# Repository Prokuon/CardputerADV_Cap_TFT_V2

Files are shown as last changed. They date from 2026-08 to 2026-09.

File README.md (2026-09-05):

# Cap TFT V2 - 2.8 Inch Display Expansion for Cardputer ADV

Cap TFT V2 is a display expansion module designed for Cardputer ADV, featuring an integrated 2.8 inch ILI9341 display (320x240)

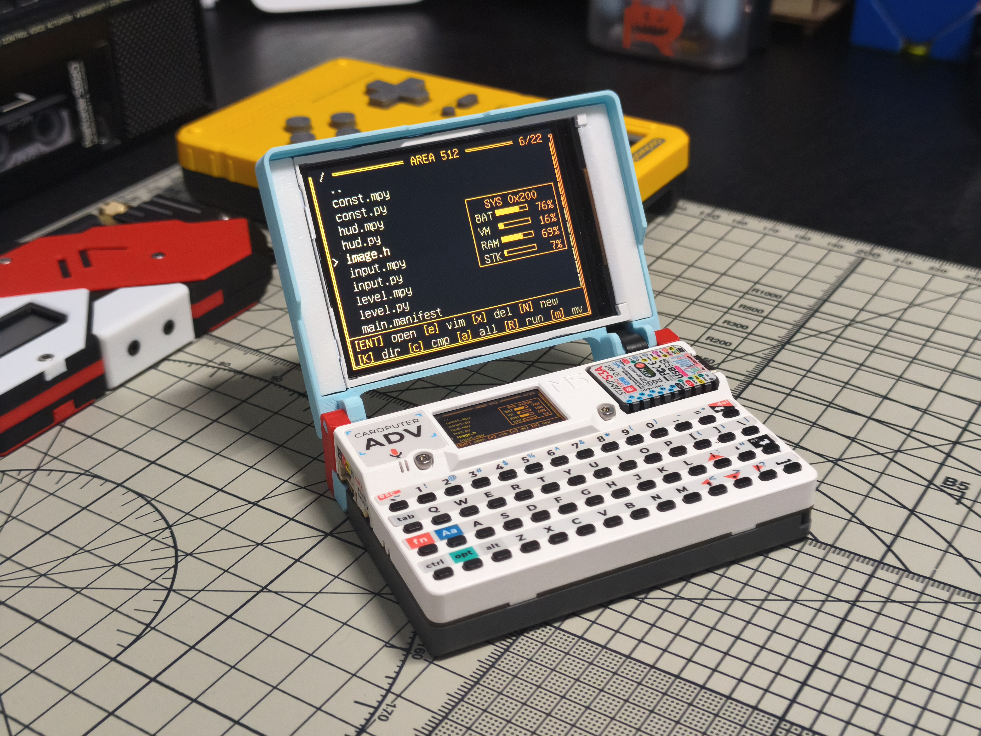
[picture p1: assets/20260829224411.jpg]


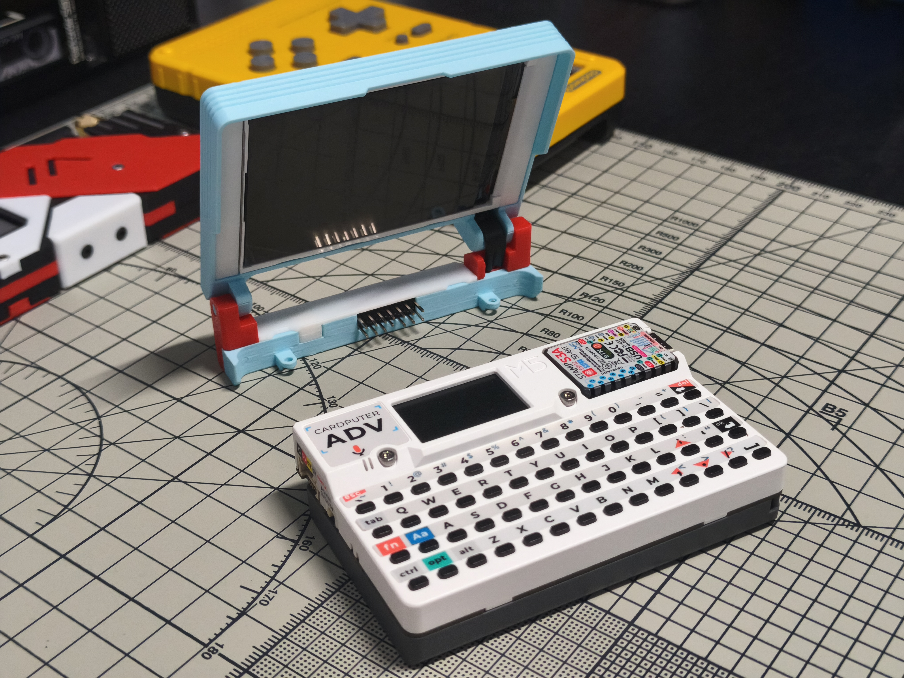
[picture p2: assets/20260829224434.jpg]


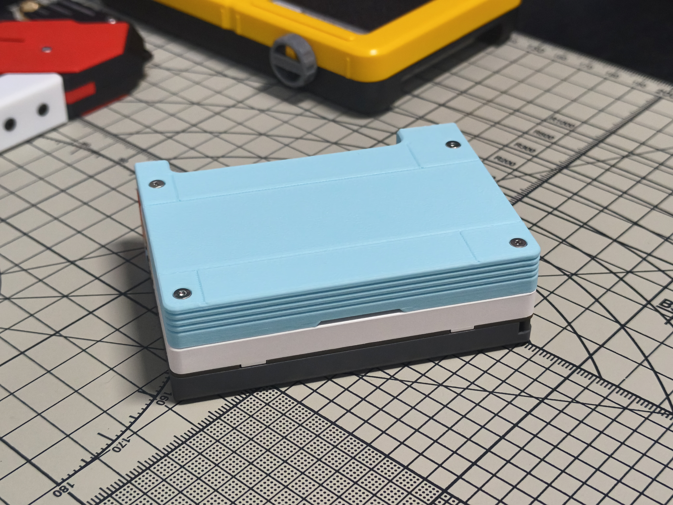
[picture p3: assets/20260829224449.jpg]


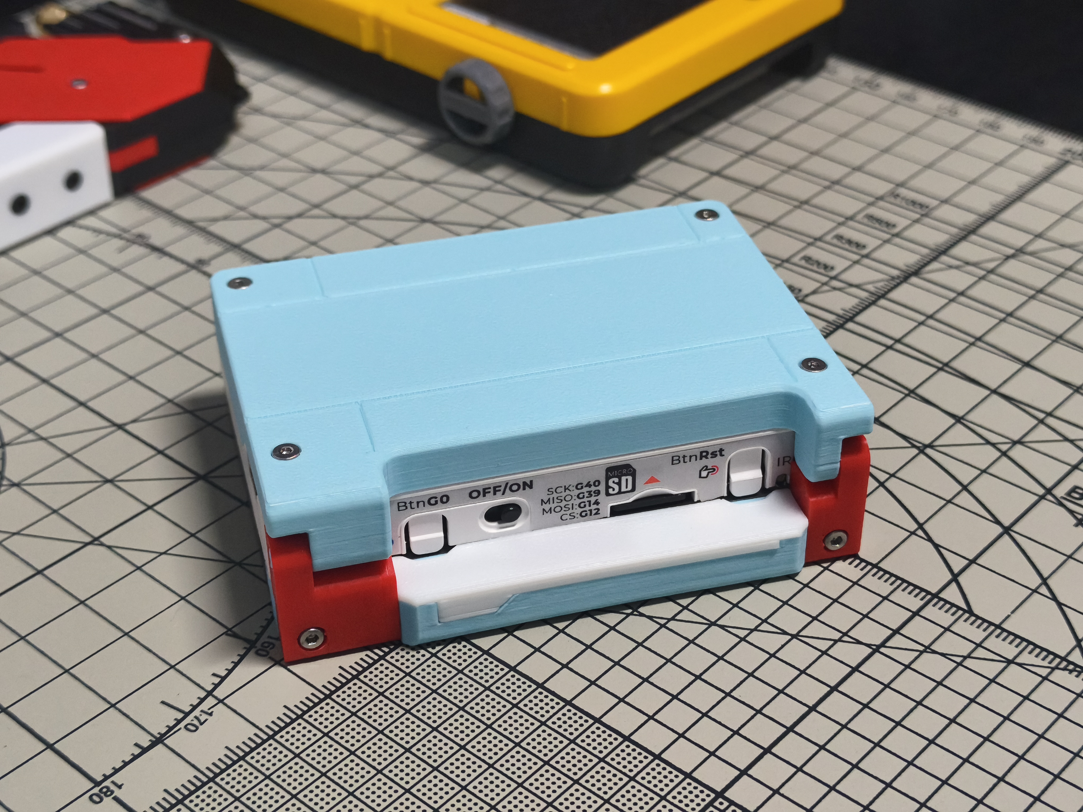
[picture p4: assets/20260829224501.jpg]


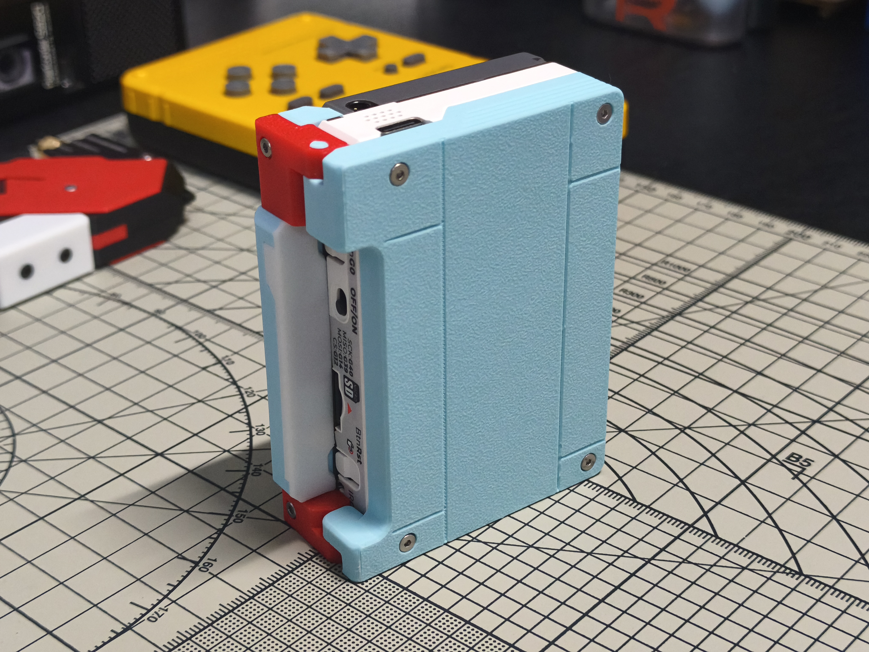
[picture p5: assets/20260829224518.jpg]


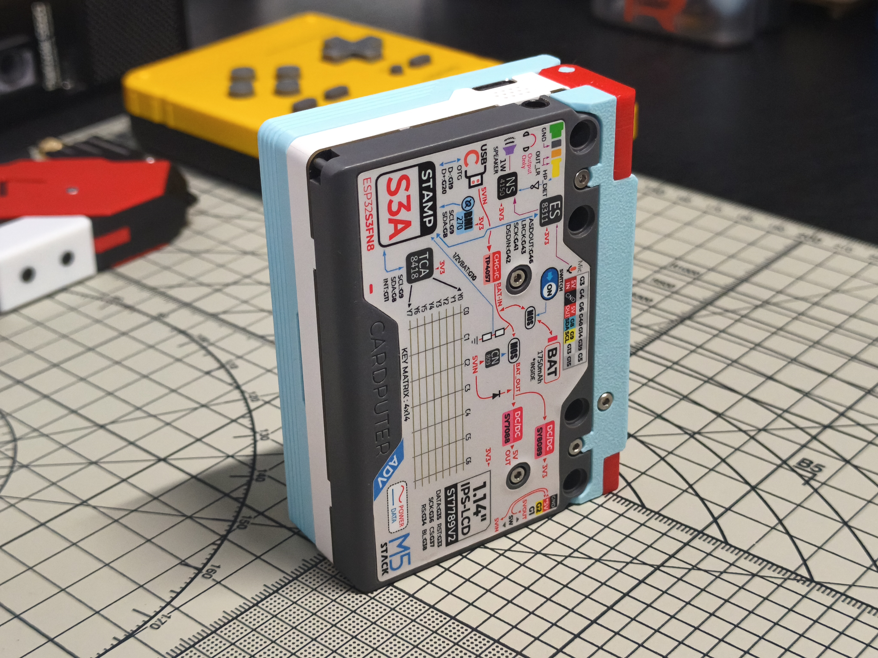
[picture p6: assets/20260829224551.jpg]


## BOM List

1. 3D printed shell D1
2. 3D printed shell D2
3. 3D printed shell D3
4. 3D printed shell L1
5. 3D printed shell R1
6. 3D printed shell S1
7. 3D printed shell C1
8. 2.8 inch ILI9341 display
9. M2x5 hex socket flat head bolts - 4 pieces
10. M2x5 hex socket cap bolts - 3 pieces
11. 2.54mm 2x7P dual-row straight pin header
12. Power supply module (AMS1117-3.3V)

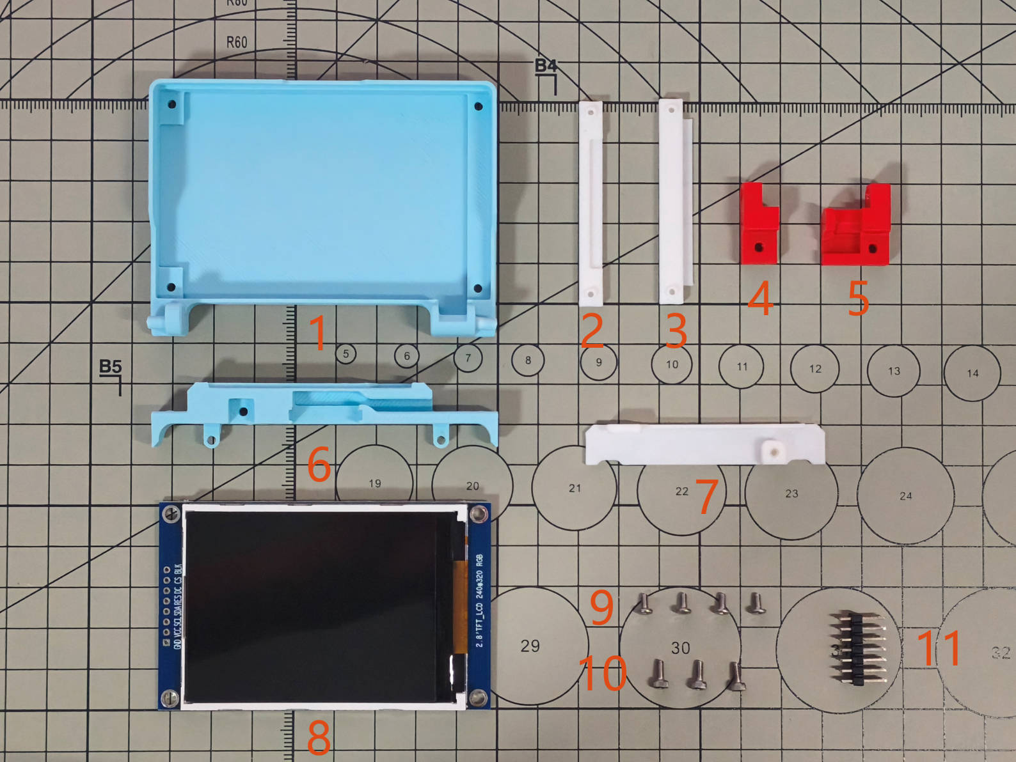
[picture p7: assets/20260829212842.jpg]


Display dimension specifications

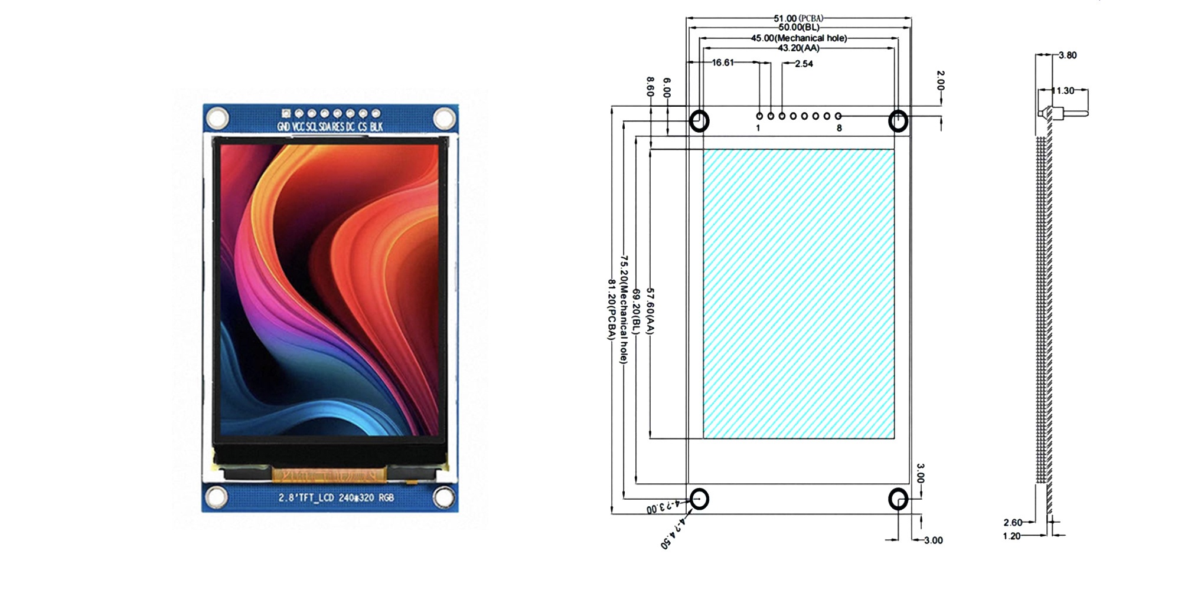
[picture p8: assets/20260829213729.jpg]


Power supply module reference image

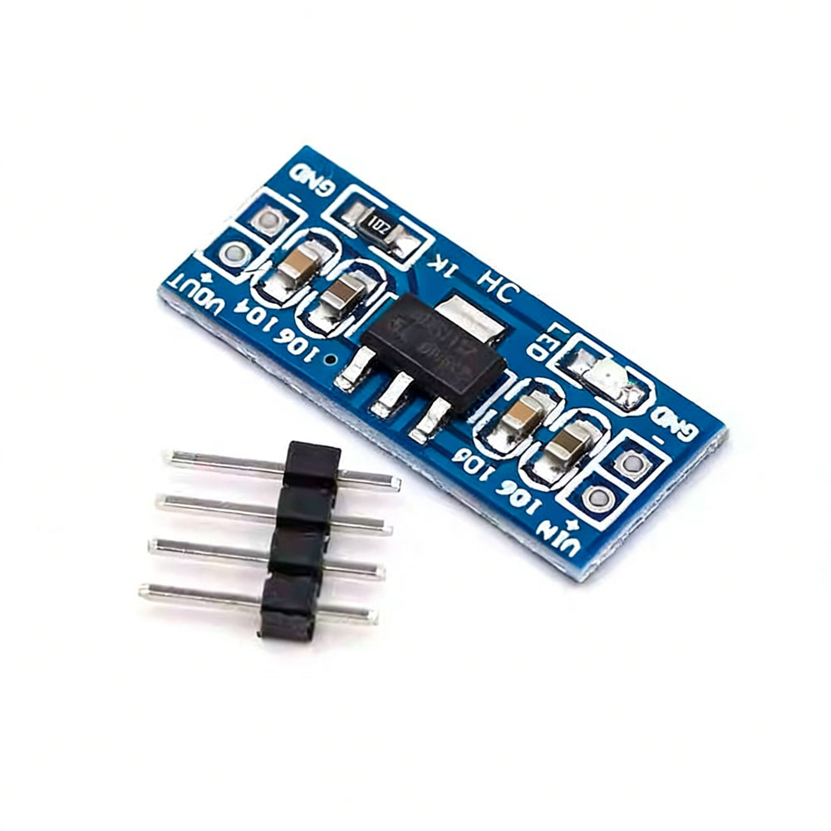
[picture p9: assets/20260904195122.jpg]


## Assembly Instructions

Attach the power supply module to the back of the display, and connect the display to the pin header using thin wires as shown in the diagram. It is recommended to use cable with an outer diameter of 0.65mm. For the wiring definition, please refer to the table below.

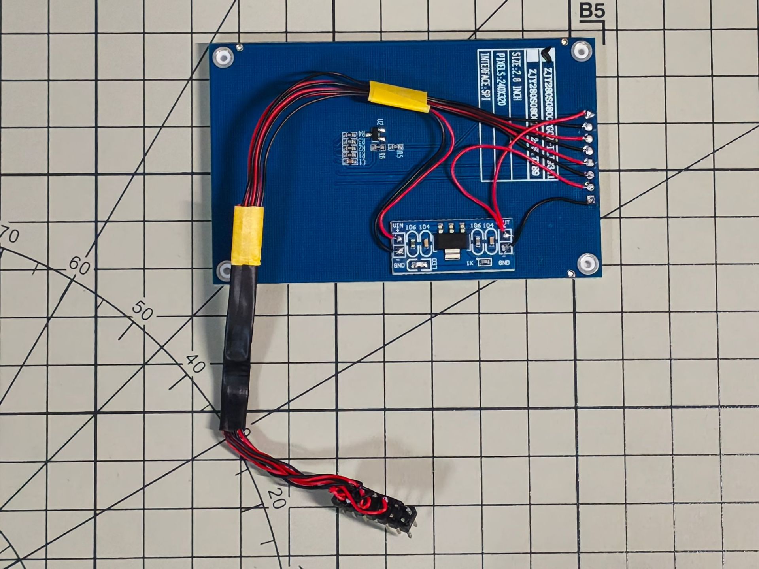
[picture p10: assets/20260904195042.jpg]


Display

| GND  | VCC  | SCL  | SDA  | RES  | DC | CS | BLK  |
| :--: | :--: | :--: | :--: | :--: | :--: | :--: | :--: |
| 1 | 2 | 3 | 4 | 5 | 6 | 7 | 8 |

Power supply module

| VIN  | VOUT |
| :--: | :--: |
| 10 | 2, 8 |
| GND  | GND  |
| 9 | 1 |

Cardputer

| G3 | G4 | G6 | G40  | G14  | G39  | G5 |
| :--: | :--: | :--: | :--: | :--: | :--: | :--: |
| 5 | x | 6 | 3 | 4 | x | 7 |
| 5VIN | GND  | 5VOUT| SDA  | SCL  | G13  | G15  |
| x | 9 | 10 | x | x | x | x |

Install the display onto D1

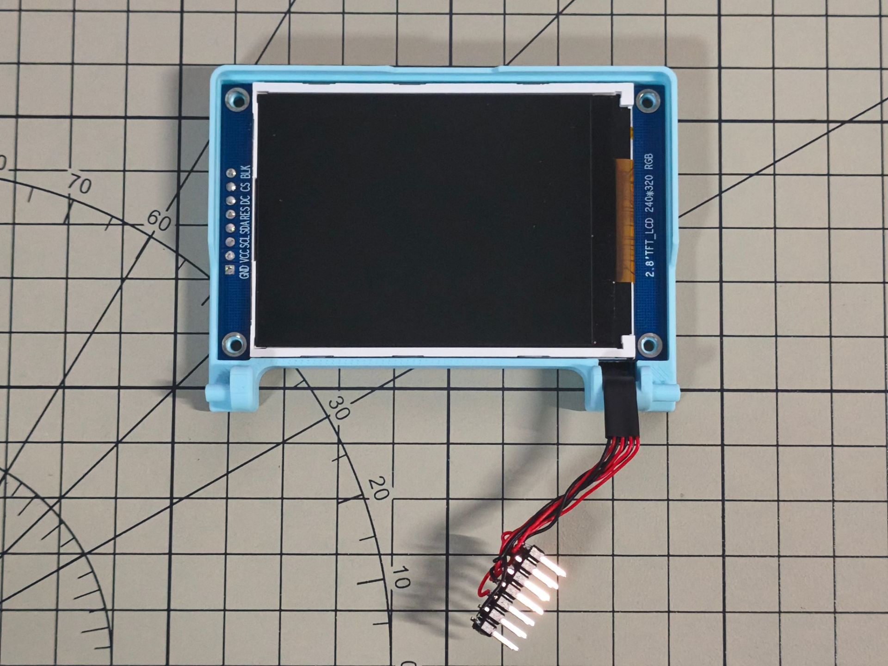
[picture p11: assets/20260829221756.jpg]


Use 4 M2x5 hex socket flat head bolts to install D2 and D3 onto D1

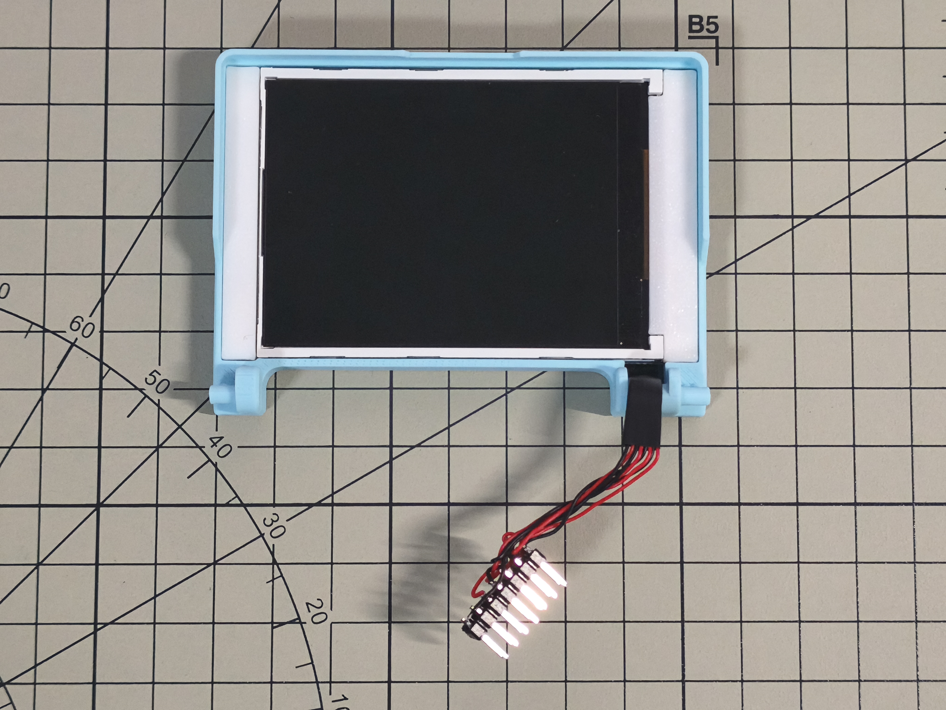
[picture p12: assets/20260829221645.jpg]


Install the pin header onto S1

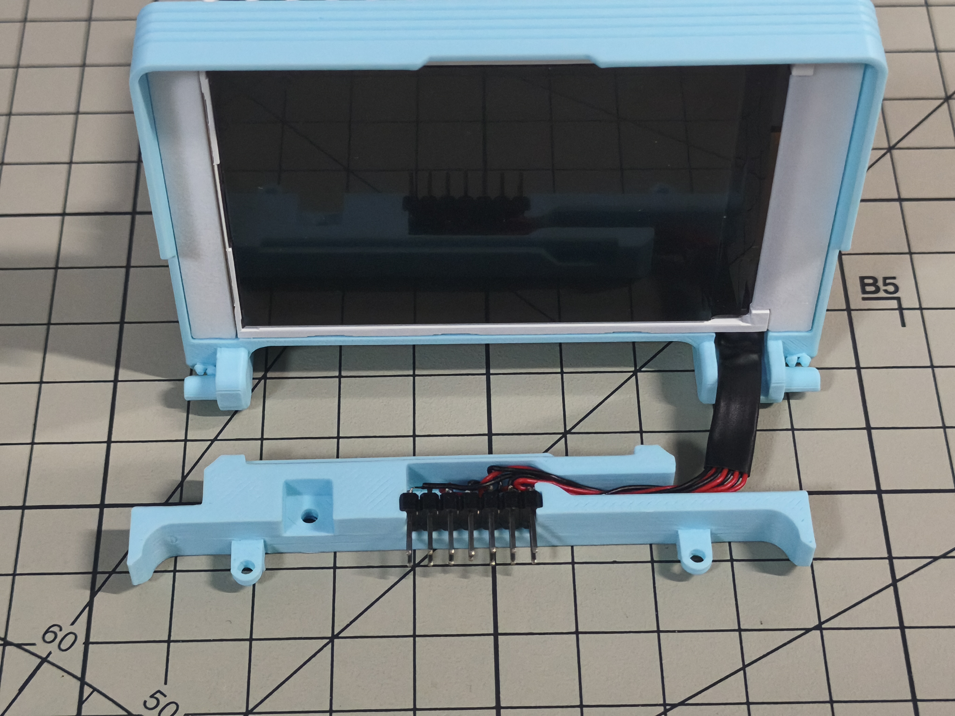
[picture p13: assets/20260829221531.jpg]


Use 1 M2x5 hex socket cap bolt to assemble C1 and S1

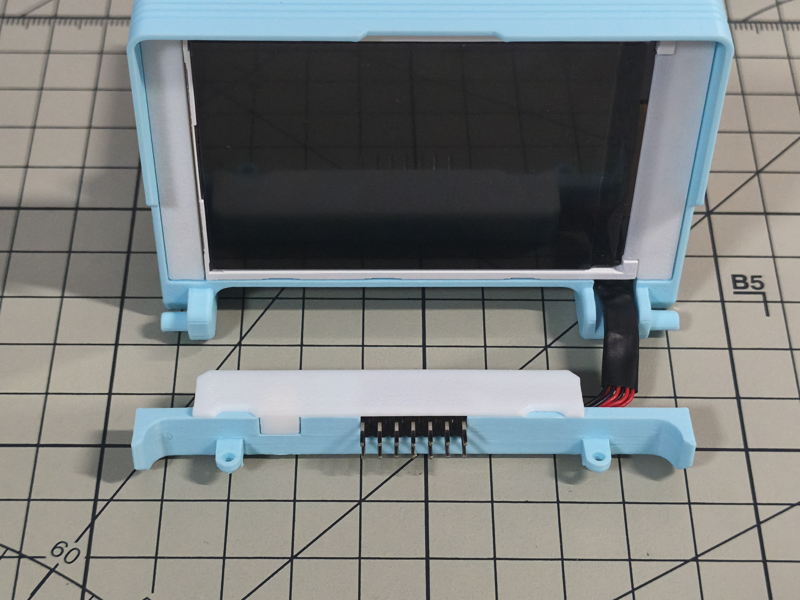
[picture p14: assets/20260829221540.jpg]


Install L1 and R1 onto D1

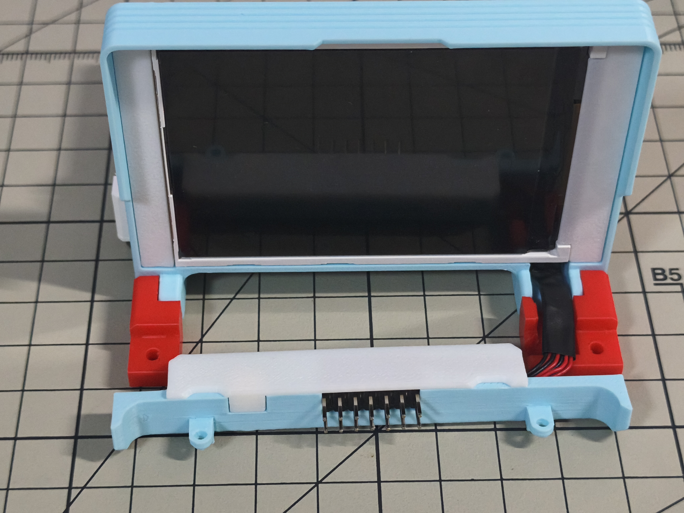
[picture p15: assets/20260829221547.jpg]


Use 2 M2x5 hex socket cap bolts to install L1 and R1 onto S1

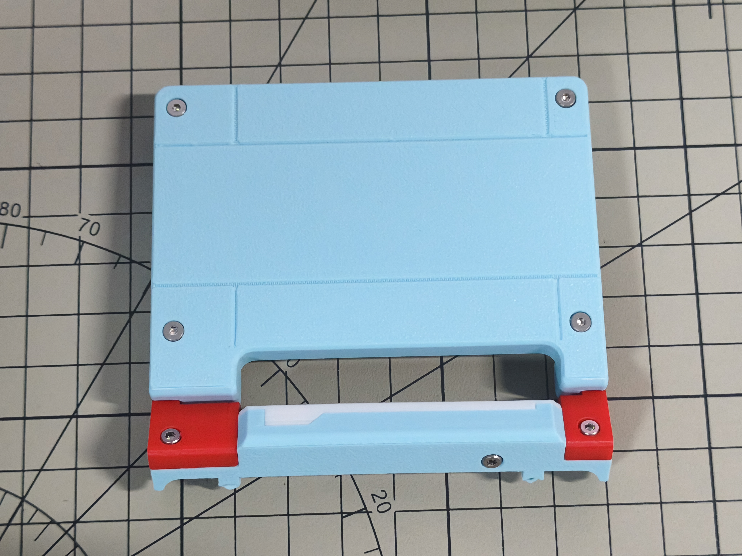
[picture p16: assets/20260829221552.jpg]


Assembly complete

## Credits

- The selection of the new display was inspired by the expansion screen designed by tipflow for Cardputer ADV. Project link: [M5 Cardputer Extended Screen](https://makerworld.com/zh/models/3054465-m5-cardputer-extended-screen?from=search#profileId-3436513)
- The firmware used for the display expansion is modified based on engneer-hamachan's [area512](https://github.com/engneer-hamachan/area512). It is a great retro OS, styled similarly to the handheld Cyberdeck used by the TVA in the TV series Loki

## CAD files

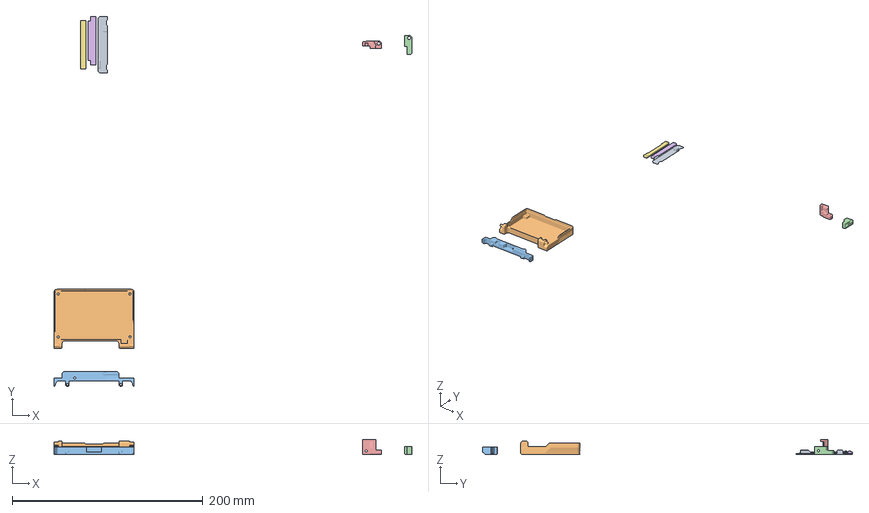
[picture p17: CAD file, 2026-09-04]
Model/CapTFT_V2.3mf
375.2 x 387.8 x 16.0 mm
CaseC1.stl
CaseD1.stl
CaseS1.stl
CaseL1.stl
CaseR1.stl
CaseD3.stl
CaseD2.stl

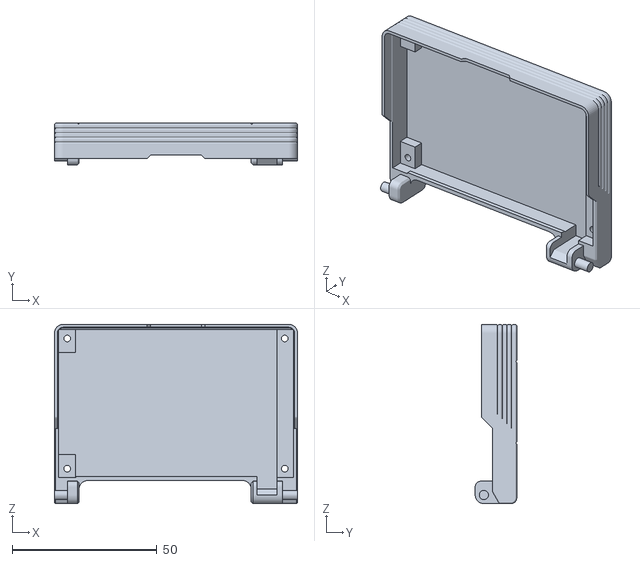
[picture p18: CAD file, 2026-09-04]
Model/STL/CaseD1.stl
84.0 x 14.4 x 62.0

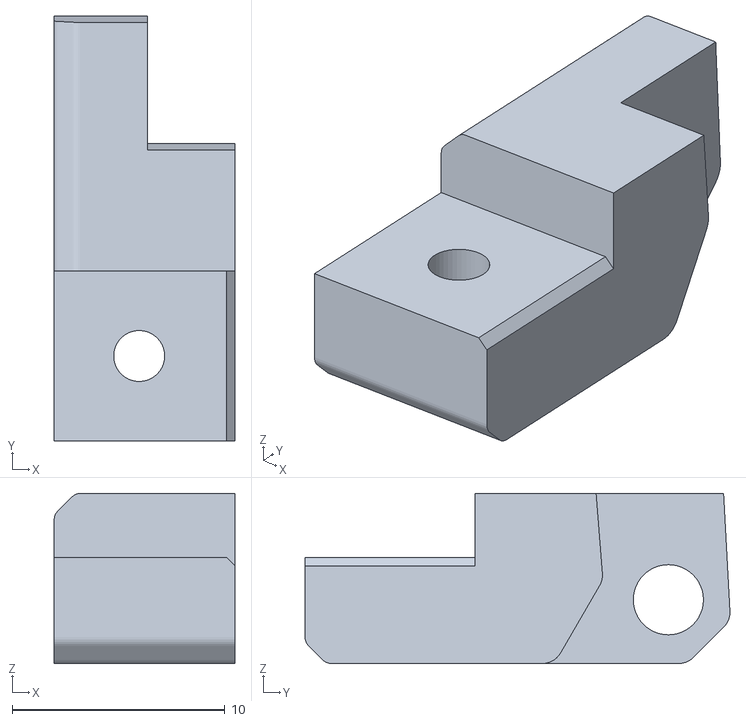
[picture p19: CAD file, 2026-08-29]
Model/STL/CaseL1.stl
8.50 x 20.0 x 8.00

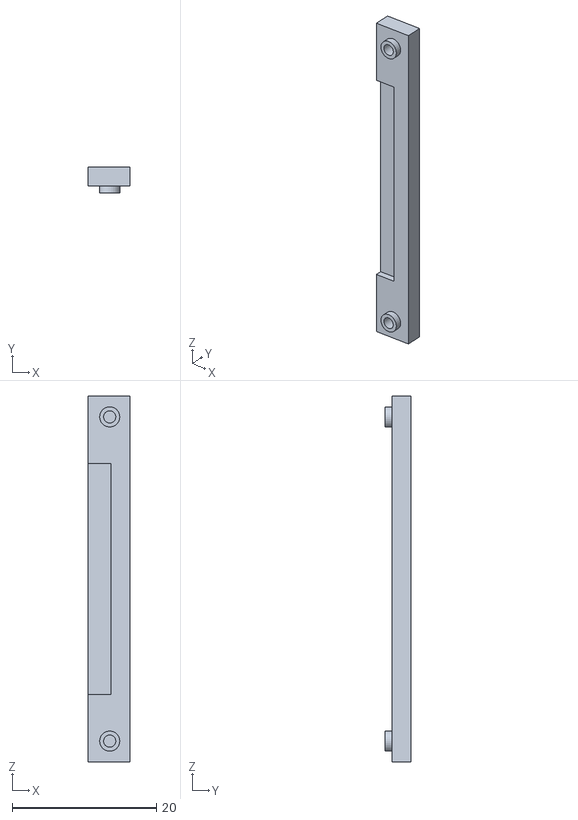
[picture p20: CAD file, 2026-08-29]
Model/STL/CaseD2.stl
5.80 x 3.60 x 50.8

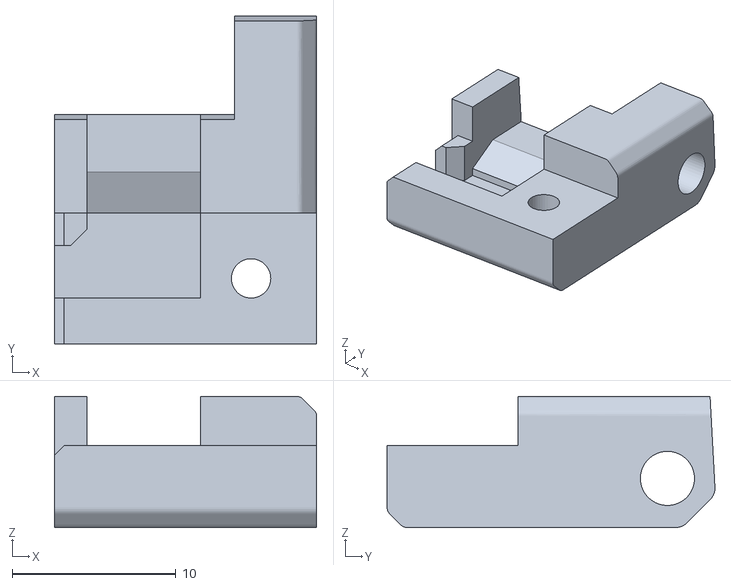
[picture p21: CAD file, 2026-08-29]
Model/STL/CaseR1.stl
16.0 x 20.0 x 8.00

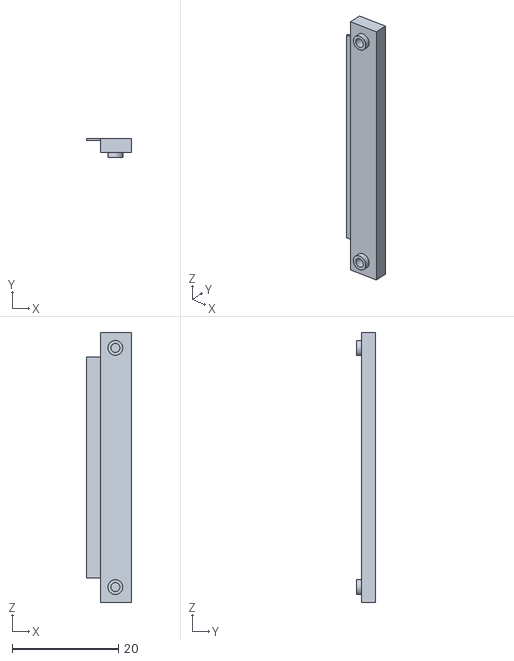
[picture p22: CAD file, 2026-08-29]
Model/STL/CaseD3.stl
8.40 x 3.60 x 50.8

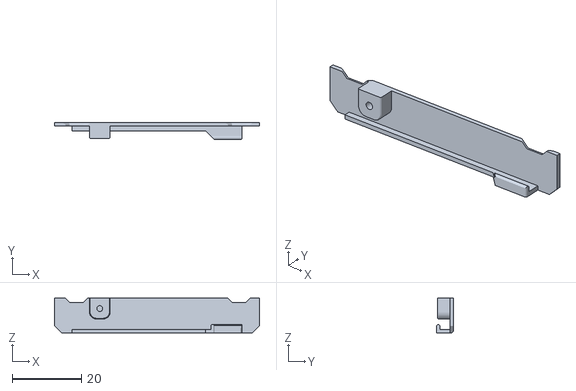
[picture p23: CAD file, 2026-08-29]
Model/STL/CaseC1.stl
59.3 x 4.90 x 10.0

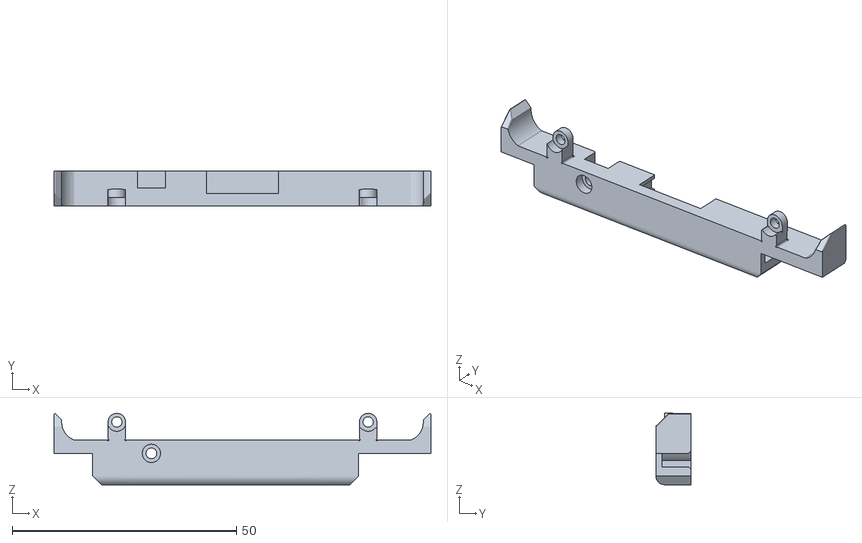
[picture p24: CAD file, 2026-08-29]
Model/STL/CaseS1.stl
84.0 x 7.90 x 16.0

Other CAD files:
Model/CapTFT_V2.f3d

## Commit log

2026-08-29 Add Model Files
    [CapTFT_V2.3mf, CapTFT_V2.f3d, CaseC1.stl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]
2026-09-04 Add AMS1117-3.3V Module
    [CapTFT_V2.3mf, CapTFT_V2.f3d, CaseD1.stl]
